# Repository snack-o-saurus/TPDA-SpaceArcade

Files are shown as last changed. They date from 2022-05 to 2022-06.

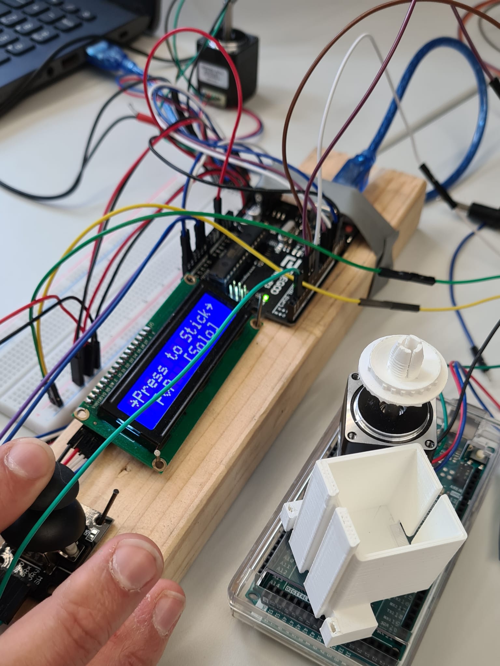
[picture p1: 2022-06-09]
Documentation/Pictures/Teiletest aus dem Druck-1/Teiltest-Testdruck1.jpeg

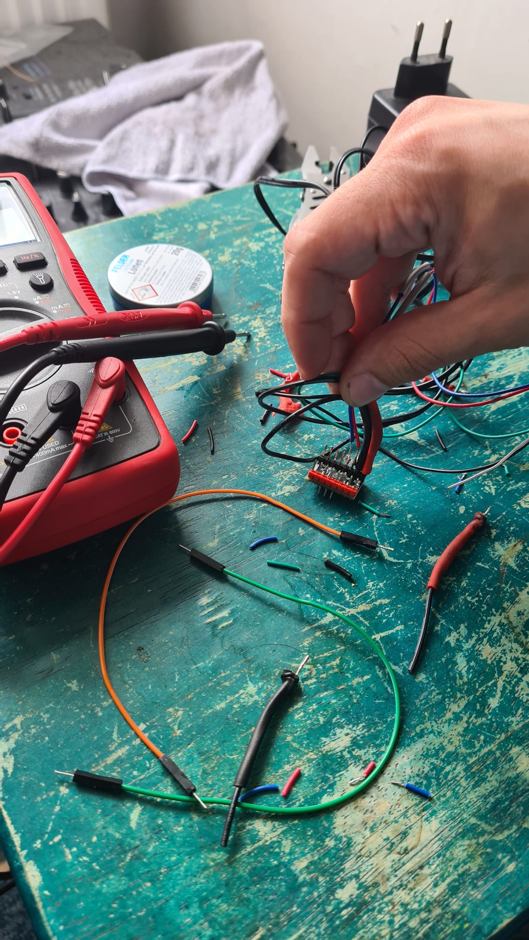
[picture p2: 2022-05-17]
Documentation/Testen-der-Schaltung-02.jpeg

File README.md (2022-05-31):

# TPDA-SpaceArcade

Gruppe 5: TPDA-W21-Oos-SpaceInvadersArcade

DEADLINE: 18. JUNI 2022
GAME JAM: 22. JUNI 2022

THIS IS THE OFFICIAL EXAM PROJECT OF THE TECHNICAL PROJECT W21 COURSE
OOMENS - TAEFI

Space Invaders Arcade Machine - Arduino Firmware Code

Dokumentation des TMC-2208-Treibers: https://github.com/teemuatlut/TMCStepper/blob/74e8e6881adc9241c2e626071e7328d7652f361a/README.md

Hier finden Sie alle nützlichen Informationen und Quellenangaben zur Umsetzung des Codes.

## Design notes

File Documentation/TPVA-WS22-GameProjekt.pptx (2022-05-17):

## TPV: Gruppe A – Oomens, Taefi Projekt: Entwicklung eines eingebetteten Games

Anselm Fritzsche – 0800-XXX
Mats Althaus – 2557483

13. Januar 2022

## Spielziel & Konzept

- Phase 1: Entwicklung eines Space Invaders – Emulators mithilfe eines Displays und eines Joysticks sowie zwei Tastern

Phase 2: Implementieren eines zweiten Terminals mit Bedienelementen – Entwicklung von Coop- und PVP-Modi

Phase 3: Entwickeln eines Interfaces mit Geschützturm, Luftballons und Zielen (angelehnt an „Jahrmarkt- bzw. Arcade-Prinzip“)

## Projektplan

Datum / Meilenstein | Ziel
13.01.2022 | Ideenfindung, Design und Projektplanung (Termine)
20.01.2022 | Projektanalyse, Entwicklung des Konzepts, Schaltskizze, Use Case-Diagramm, Aktivitätsdiagramme, Festlegen des Spielziels, Entwicklung von Konzept & Bedienkonzept
27.01 2022 | Vorstellung des Projekts: Erreichen des 1/3 − Meilensteins (1)
03.02.2022
10.02.2022
17.02.2022
24.02.2022
03.03.2022
10.03.2022
17.03.2022
24.03.2022
31.03.2022
07.04.2022
14.04.2022
21.04.2022
28.04.2022
05.05.2022 | Poster mit Bedienungsanleitung (?!), Upload des Codes

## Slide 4

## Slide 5

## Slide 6

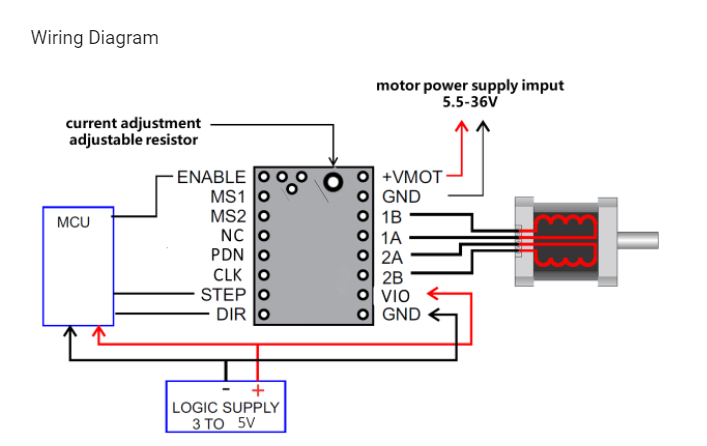
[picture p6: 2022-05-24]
schematic/TMC-2208-Interfaceschematic.png

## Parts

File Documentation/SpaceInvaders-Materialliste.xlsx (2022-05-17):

 | Space Invaders-Simulator: Materialliste
 |  |  | Option 1: Schrittmotoren, evidence based proof
Menge | Bezeichnung | Preis/Stk | Bezug | Summe
1 | 3D-Drucker-Bausatz (inkl. 4x Schrittmotor, Treiber, 2. Arduino Uno | 44.28 € | https://www.wish.com/search/stepper%20motor/product/5d71d7c4bddcd87e079ee16d?position=0&share=web | 44.28 €
10 | Hall-Sensor (10Stk@5,00€) | 0.50 € | https://www.wish.com/search/hall%20sensor/product/610667652d587eca89de3e1e?position=1&share=web | 5.00 €
1 | NERF-Pistole zum Zerlegen | 4.50 € | https://www.ebay.de/itm/194788540224?hash=item2d5a4d3f40:g:pGcAAOSw4N1h-Wlu | 4.50 €
1 | TFT-Display für Uno R3 | 8.00 € | https://www.wish.com/search/tft%20display/product/60056a0869809fbace21e8d7?position=6&share=web | 8.00 €
 |  |  | vorauss. Versandkosten: | 10.00 €
 |  |  | vorauss. Gesamtsumme: | 71.78 €
 |  |  | Option 2: Getriebemotoren, PWM-Regelung (stufenlos), Umsetzung nach Plan
2 | 12V-Getriebemotor mit Spindel | 7.95 € | https://www.pollin.de/p/getriebemotor-5503740-12v-spindel-310842 | 15.90 €
2 | 12V / 32mA DC Schrittmotor, Winkel 5,625 | 12.95 € | https://de.elv.com/schrittmotor-12-v-dc-32-ma-winkel-5625-64-schritte-109085?fs=3090392678&c=487 | 25.90 €
1 | Arduino MotorShield (Motortreiber) | 12.95 € | https://www.pollin.de/p/joy-it-motorshield-fuer-arduino-810662 | 15.50 €
10 | INFINEON Hallsensor TLE 4905L | 0.62 € | https://de.elv.com/infineon-hallsensor-tle-4905l-109561?fs=3255545492&c=840 | 6.20 €
1 | AU-Optronics M156XW01 LC-TFT-Display 1366x768@15,6" | 9.95 € | https://www.pollin.de/p/lc-display-au-optronics-m156xw01-15-6-16-9-lvds-121776 | 9.95 €
1 | NERF-Pistole zum Zerlegen | 4.50 € | https://www.ebay.de/itm/194788540224?hash=item2d5a4d3f40:g:pGcAAOSw4N1h-Wlu | 4.50 €
 |  |  | vorauss. Versandkosten: | 15.00 €
 |  |  | vorauss. Gesamtsumme: | 92.95 €
 |  |  | = lange Lieferzeit
 |  |  | = Alternative

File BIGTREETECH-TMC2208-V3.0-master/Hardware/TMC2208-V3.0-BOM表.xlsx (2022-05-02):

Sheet: Sheet1
TMC2208-V3.0 BOM表
物料编号 | 元件型号 | 元件丝印位置 | 元件封装 | 数量 | 备注
贴片料
DDZ000046 | 0.11R 1% | R6, R7 | 0805R | 2 | 贴片电阻
DDZ000082 | 0R | J2 | 0402A | 1 | UART
DDZ000077 | 20K | R1, R2, R3, R5 | 0402A | 4 | 贴片电阻
DDW000019 | 20K | RP1 | VR6 | 1 | 可调电位器
DDR000033 | 0.1UF/50V/±10% | C1, C3, C5, C6 | 0402A | 4 | 贴片电容
DDR000022 | 10UF/50V/±10% | C7 | 0603N | 1 | 贴片电容
DDR000052 | 22NF/50V/±10% | C4 | 0402A | 1 | 贴片电容
DDR000037 | 4.7UF/10V/±10% | C2 | 0402A | 1 | 贴片电容
DIC000049 | TMC2208 | IC1 | QFN28 | 1 | IC
DPC000150 | TMC2208-V3.0 |  |  | 1 | PCB
制表： 姜坤 批准：
时间：2019.3.30 时间：

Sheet: Sheet2
插件料
物料编号 | 元件型号 | 元件丝印位置 | 元件封装 | 数量 | 备注
DPZ000249 | 8Pin 2.54mm | JP1 | 8HEARD | 1 | 黑色镀金单排排针
DPZ000250 | 8Pin 2.54mm | JP2 | 8HEARD | 1 | 蓝色镀金单排排针
BQT000034 | 防静电盒 |  |  | 1 | 包装袋盒
MPA000109 | TMC2208-V3.0 |  |  | 1 | PCBA
WSR000012 | 散热片 |  | 9*9*12 | 1 | 黑色散热片
BQT000043 | TMC2208卡片 |  |  | 1
制表： 姜坤 批准：
时间：2019.3.30 时间：

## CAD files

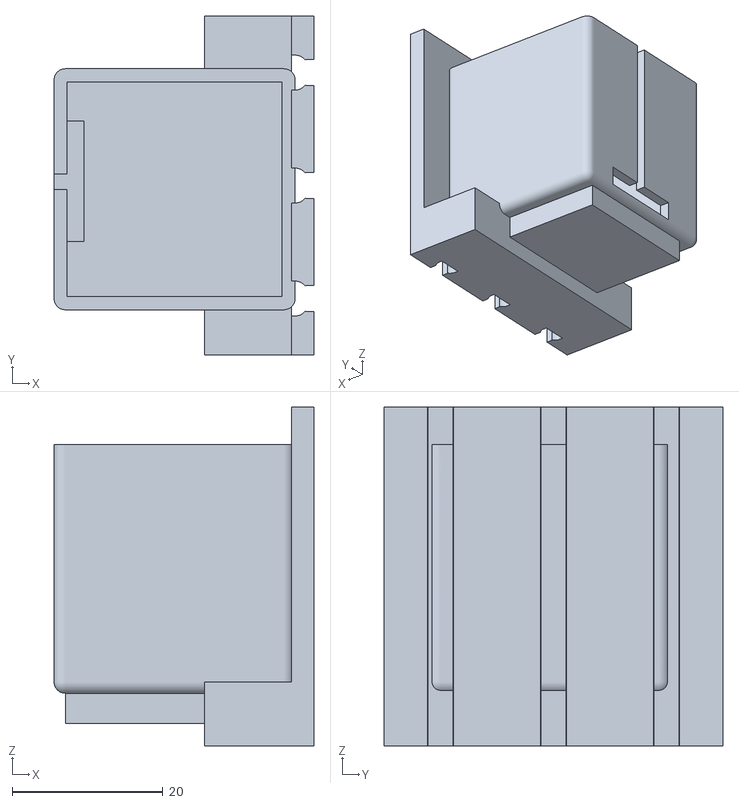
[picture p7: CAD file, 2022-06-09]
models/Druck01_v3/Motor-PAN-Case-v3.stl
34.5 x 45.0 x 45.0

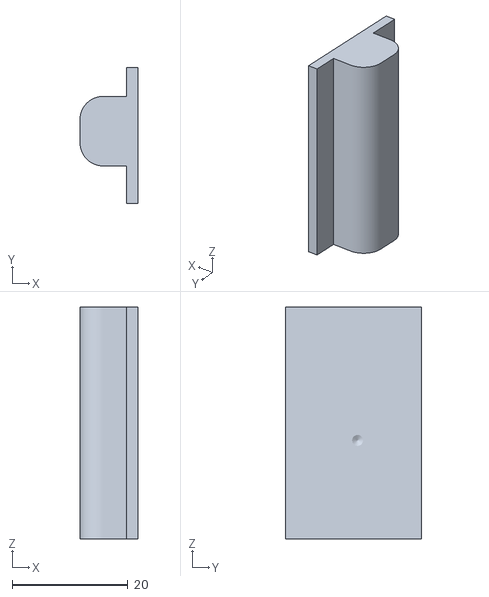
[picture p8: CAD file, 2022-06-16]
models/Druck02_v3/Stempel-R.stl
10.0 x 23.5 x 40.0

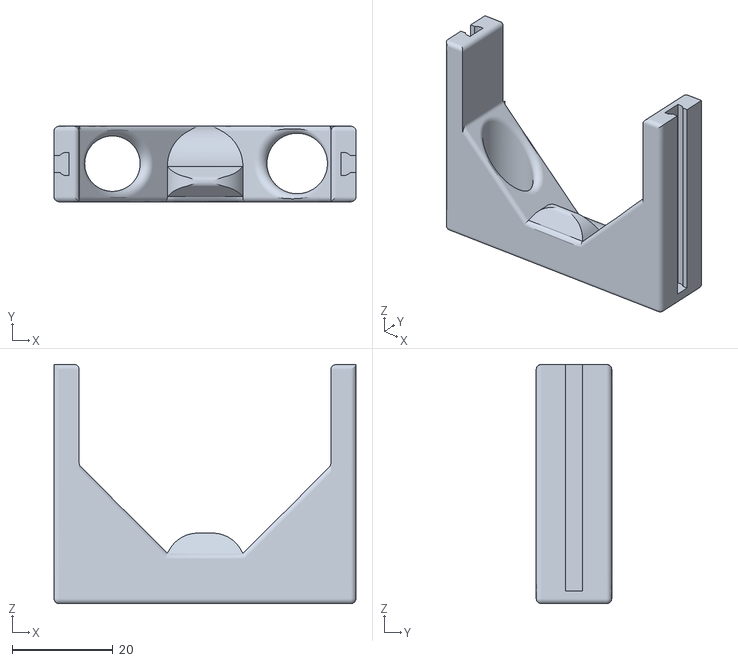
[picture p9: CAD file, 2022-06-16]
models/Prototype #1/Nerfhalter-Grip-v3.stl
60.0 x 15.0 x 47.5

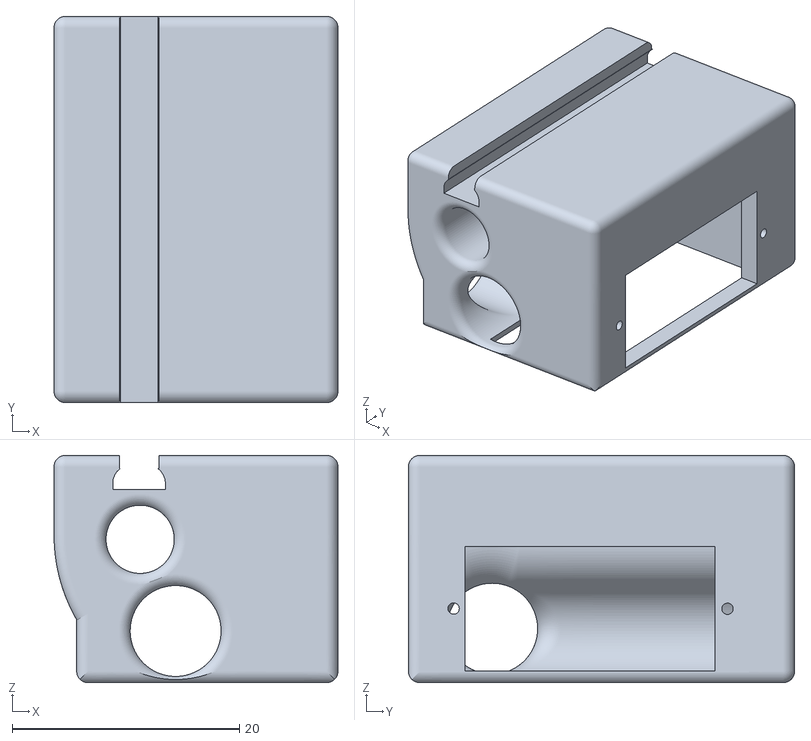
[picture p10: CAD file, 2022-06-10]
models/Prototype #2/Servobefestigung-v5.stl
25.0 x 34.0 x 20.0

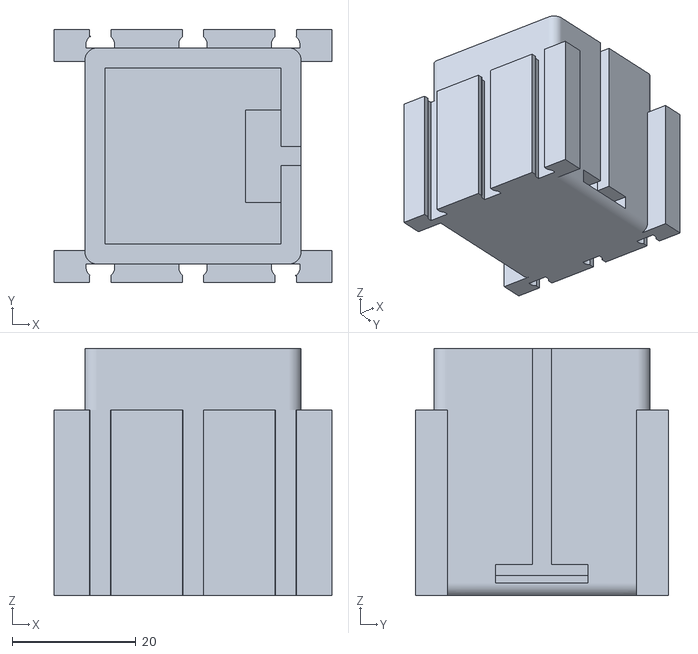
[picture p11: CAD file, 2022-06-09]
models/Druck01_v3/Motor-TILT-Case-v3.stl
45.0 x 41.0 x 40.0

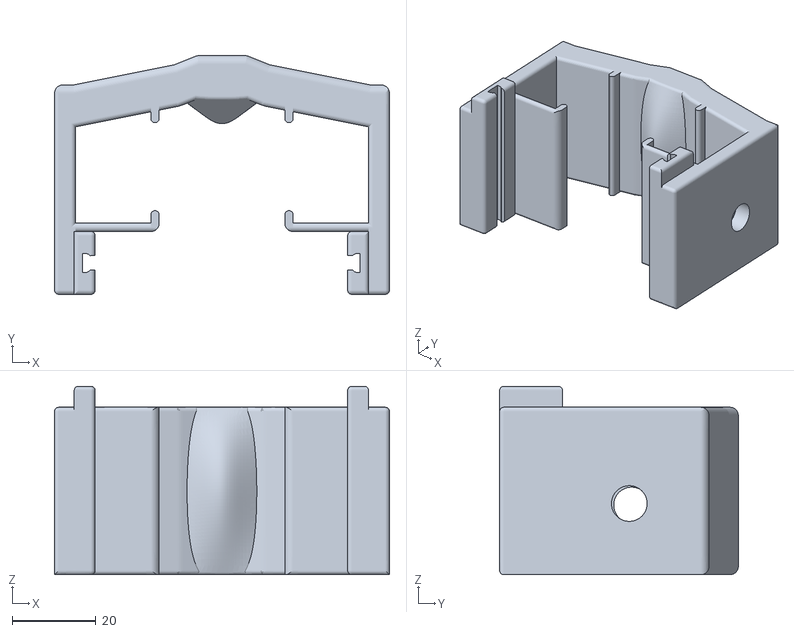
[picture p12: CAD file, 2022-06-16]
models/Druck02_v3/Laufhalter-NERF-v2.stl
80.0 x 57.0 x 45.0

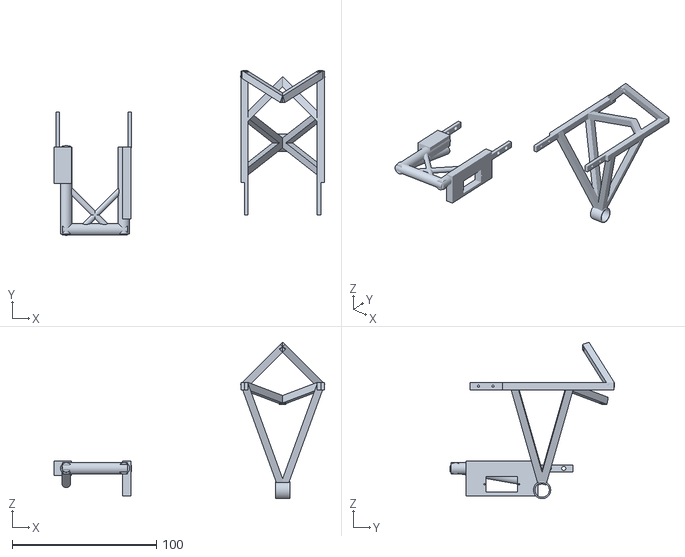
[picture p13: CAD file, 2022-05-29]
models/Prototype #1/NerfTurret-ProTyp-Fixation-4-v2.stl
187.9 x 114.1 x 108.4

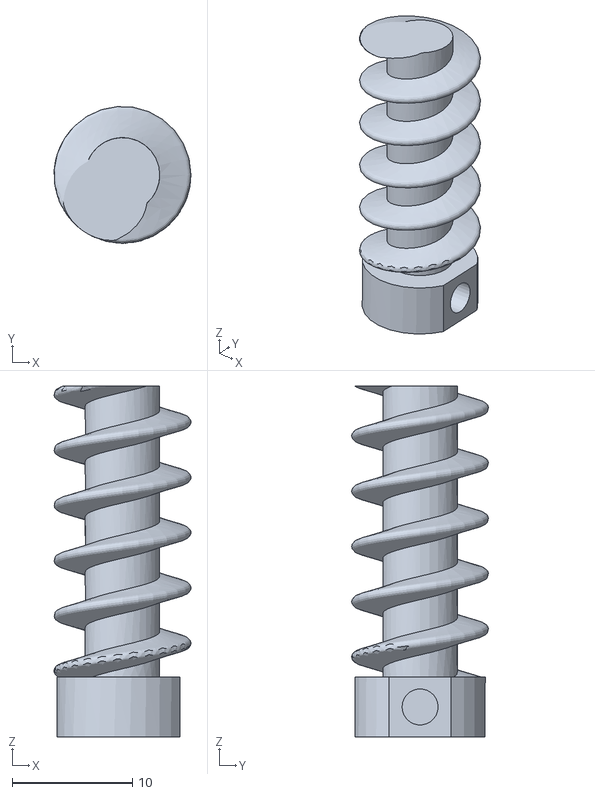
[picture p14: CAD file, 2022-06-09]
models/Druck01_v3/Wormgear-Adaptor-v3.stl
11.4 x 11.4 x 29.2

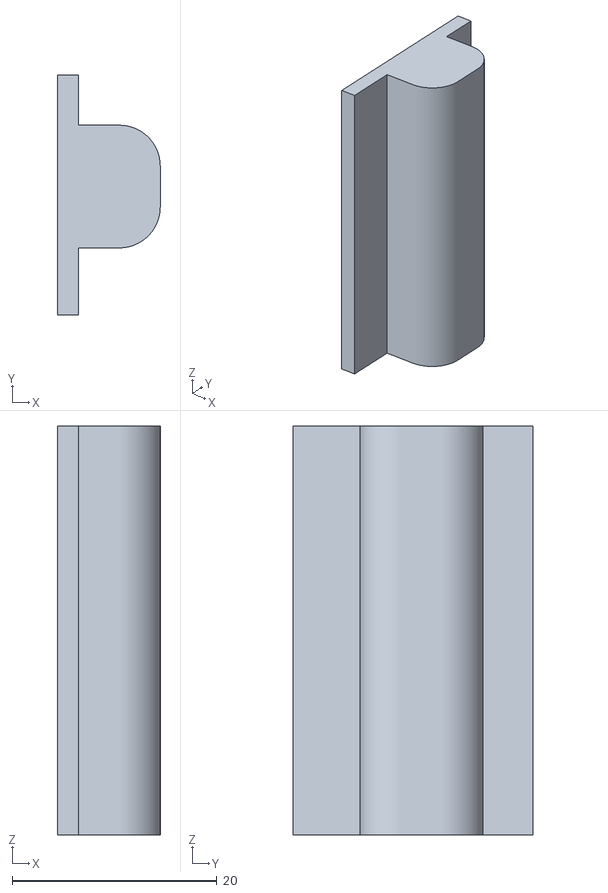
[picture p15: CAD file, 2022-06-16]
models/Druck02_v3/Stempel-L.stl
10.0 x 23.5 x 40.0

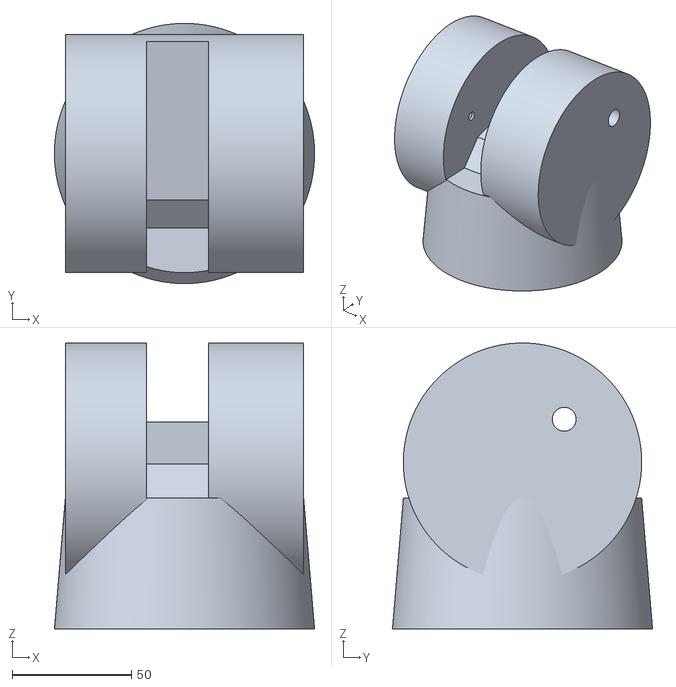
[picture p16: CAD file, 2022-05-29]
models/Prototype #1/NerfTurret-ProTyp-Turret-2-v2.stl
109.2 x 109.2 x 120.0

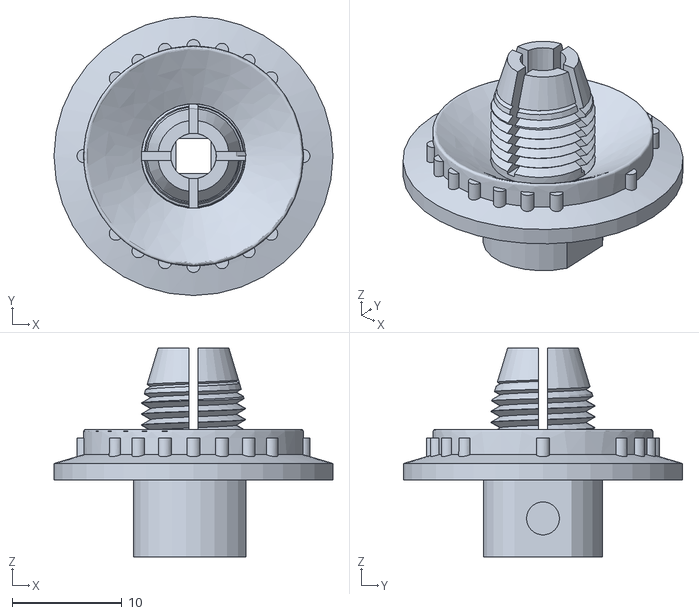
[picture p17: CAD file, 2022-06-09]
models/Druck01_v3/Gear-Adaptor-v3.stl
25.4 x 25.4 x 19.0

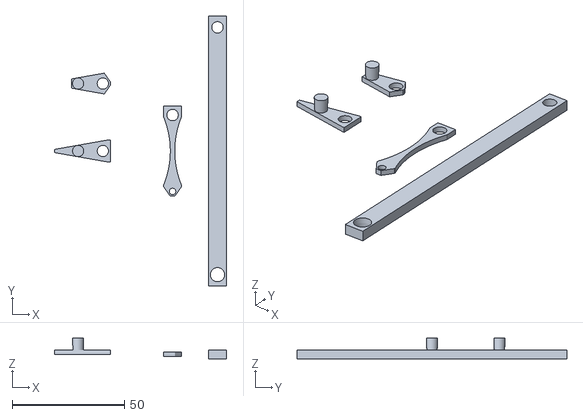
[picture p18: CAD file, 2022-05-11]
models/Prototype #1/NerfTurret-ProTyp-Connectors-3.stl
76.5 x 120.0 x 9.25

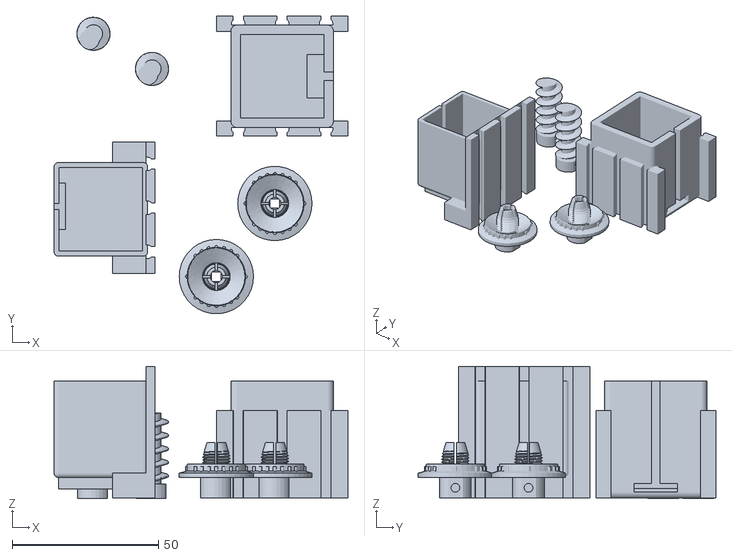
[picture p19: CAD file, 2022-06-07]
models/Druck01_v3/SpaceParts-v3.stl
100.5 x 101.7 x 45.2

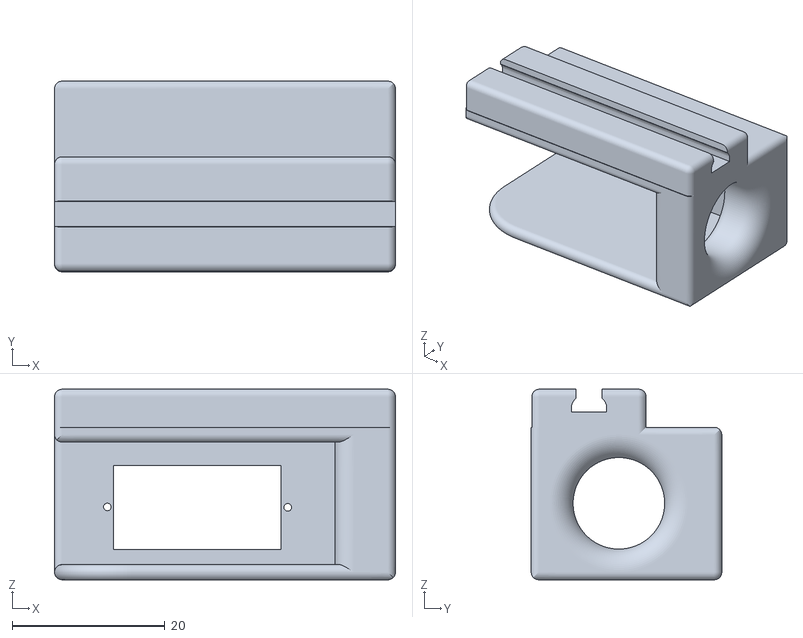
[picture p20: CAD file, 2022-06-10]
models/Druck02_v3/Servohalter-v4.stl
44.7 x 25.0 x 25.0

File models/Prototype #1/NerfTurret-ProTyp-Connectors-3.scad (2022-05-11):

$fn = 250;

//Adapter fuer Motorwelle PAN
difference(){
translate([-200,0,1]){cube([25,10,2], center=true);}
translate([-200,8,1]){
    rotate([0,0,10]){cube([40,10,3], center=true);}}
translate([-200,-8,1]){
    rotate([0,0,-10]){cube([40,10,3], center=true);}}
translate([-191,0,1]){cylinder(12,2.5,2.5,true);}}
translate([-202,0,4.5]){cylinder(5.5,2.3,2.5,true);}
//----------------------------------------------------------
//Adapter fuer Motorwelle TILT
difference(){
translate([-200,30,1]){cube([25,10,2], center=true);}
translate([-200,38,1]){ rotate([0,0,10]){
    cube([40,10,3], center=true);}}
translate([-200,22,1]){ rotate([0,0,-10]){
    cube([40,10,3], center=true);}}
translate([-180.5,38,1]){ rotate([0,0,35]){
    cube([20,10,3], center=true);}}
translate([-180.5,22,1]){ rotate([0,0,-35]){
    cube([20,10,3], center=true);}}
translate([-191,30,1]){cylinder(12,2.5,2.5,true);}
translate([-210,30,1]){cube([10,10,3], center=true);}
}
translate([-202,30,4.5]){cylinder(5.5,2.3,2.5,true);}
//----------------------------------------------------------
//Verbindungsstange PAN
//TODO: Radien nach Spiel einstellen!!!
difference(){
translate([-140,0,0]){cube([8,120,4], center=true);}
translate([-140,55,0]){cylinder(20,2.5,2.6,center=true);}
translate([-140,-55,0]){cylinder(20,2.5,3.8,center=true);}
translate([-140,-55,0]){cylinder(20,3.8,2.5,center=true);}
}
//-----------------------------------------------------------
//Verbindungsstange TILT
//TODO: Radien nach Spiel einstellen!!!
difference(){
translate([-160,0,0]){cube([8,40,2], center=true);}
translate([-160,16,0]){cylinder(20,2.5,2.6,center=true);}
translate([-160,-18,0]){cylinder(10,1.2,1.7,center=true);}
translate([-160,-18,0]){cylinder(10,1.7,1.2,center=true);}
translate([-166.5,-21,0]){    rotate([0,0,-55]){
    cube([10,10,3],center=true);}}
translate([-153.5,-21,0]){    rotate([0,0,55]){
    cube([10,10,3],center=true);}}
translate([-201,0,0]){cylinder(10,40,40,center=true);}
translate([-119,0,0]){cylinder(10,40,40,center=true);}
}

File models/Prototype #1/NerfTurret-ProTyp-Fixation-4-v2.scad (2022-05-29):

$fn = 300;

//Halterung NERF
 rotate([0,90,0]){
 difference(){  cylinder(10,6,6,center=true);  
                cylinder(11,5,5,center=true);}}
                
//Nerfhalter v.2 [Anforderungen prov. by Oos, 
//neuer Prototyp sei erforderlich zur Druckoptimierung]
// >>24/5/22
//------------------------------------------------------------
//VL                
translate([-14,10,39]){ rotate([-15,-20,0]){
  cube([5,5,75],center=true);   }}
//VR
translate([14,10,39]){ rotate([-15,20,0]){
  cube([5,5,75],center=true);   }}
//HL
translate([-14,-10,39]){ rotate([15,-20,0]){
  cube([5,5,75],center=true);   }}
//HR
translate([14,-10,39]){ rotate([15,20,0]){
  cube([5,5,75],center=true);   }}
//RL
difference(){
translate([-26.5,0,72]){  rotate([0,0,0]){
  cube([5,100,5],center=true);  }}
translate([-30,-40,72]){   rotate([0,0,0]){
  cube([7,25,7],center=true);   }}
translate([0,-44,72]){   rotate([0,90,0]){
 cylinder(60,0.75,0.75,center=true);  }}
translate([0,-34,72]){   rotate([0,90,0]){
 cylinder(60,0.75,0.75,center=true);  }}}
//RR
  difference(){
translate([26.5,0,72]){  rotate([0,0,0]){
  cube([5,100,5],center=true);  }}
translate([30,-40,72]){  rotate([0,0,0]){
  cube([7,25,7],center=true);   }}
translate([0,-44,72]){   rotate([0,90,0]){
 cylinder(60,0.75,0.75,center=true);  }}
translate([0,-34,72]){   rotate([0,90,0]){
 cylinder(60,0.75,0.75,center=true);  }}}
//LC
translate([-12.5,30,67]){    rotate([-15,0,-45]){
    cube([5,40,5],center=true); }}
translate([12.5,30,67]){    rotate([-15,0,45]){
    cube([5,40,5],center=true); }}
//STC
translate([-13,39,86]){   rotate([-66,45,0]){
    cube([5,43,5],center=true); }}
translate([13,39,86]){   rotate([-66,-45,0]){
    cube([5,43,5],center=true); }}
//---------------------------------------------------------
//Back frame
translate([-150,0,0]){    union(){
translate([40,-33,15]){  rotate([90,0,0]){
    cylinder(60,4,4,center=true);}}
translate([0,-33,15]){  rotate([90,0,0]){
    cylinder(60,4,4,center=true);}}
translate([20,-60,15]){  rotate([90,0,90]){
    cylinder(45,4,4,center=true);}}
translate([15,-45,15]){  rotate([90,0,45]){
    cylinder(45,2,2,center=true);}}
translate([25,-45,15]){  rotate([90,0,-45]){
    cylinder(45,2,2,center=true);}}
translate([0,-33,10]){  rotate([80,0,0]){
    cylinder(62,3,3,center=true);}}
    
difference(){
translate([44,8.8,15]){  rotate([0,0,0]){
   cube([2.5,25,5],center=true);}}
translate([44,15,15]){  rotate([0,90,0]){
   cylinder(50,1.45,1.45,center=true);}}
translate([44,5,15]){  rotate([0,90,0]){
   cylinder(50,1.45,1.45,center=true);}}
}
difference(){
translate([-6,8.8,15]){  rotate([0,0,0]){
   cube([2.5,25,5],center=true);
}}
translate([-6,15,15]){  rotate([0,90,0]){
   cylinder(50,1.45,1.45,center=true);}}
   
translate([-6,5,15]){  rotate([0,90,0]){
   cylinder(50,1.45,1.45,center=true);}}
}


translate([-2.5,-15.5,15]){  rotate([0,0,0]){
   cube([12,25,10],center=true);
}}

//Aufnahme fuer Triggerservo
difference(){
translate([42,-27.9,8]){cube([6,50,24],center=true);}
translate([42,-27.9,4]){cube([10,22,11],center=true);}
translate([42,-16,4]){  rotate([0,90,0]){
    cylinder(8,0.5,0.5,center=true);}}
translate([42,-40,4]){  rotate([0,90,0]){
    cylinder(8,0.5,0.5,center=true);}}
}
}}

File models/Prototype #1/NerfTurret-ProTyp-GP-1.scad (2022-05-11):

$fn=150; //Auflösung

//Erstellen der Grundplatte mit Nut
union(){    difference(){
cube([200,180,40], center=true);
//Aussparung für PAN-Servomotor 
 translate([60,60,0]){cube([29,29,45], center=true);} 
 translate([60,85,-22]){cube([5,25,10], center=true);}
 
 //Nut
 translate([0,0,37]){    
  difference(){   
    cylinder(h=40,r=50, center=true);
    cylinder(h=40,r=45, center=true); }}}
    
translate([44.5,60,22]){cube([2,30,5], center=true); } 
translate([75.5,60,22]){cube([2,30,5], center=true); } 
//Top plate for engine screwdown       
difference(){  
 translate([60,60,25]){cube([33,30,2], center=true);}  
    // 1/1000 clearance for engine shaft 
 translate([60,60,25]){cylinder(5, 2.6, center=true);}
    //Screwdown points
 translate([50,70,25]){cylinder(5, 2.5, center=true);}
 translate([70,70,25]){cylinder(5, 2.5, center=true);}
 translate([70,50,25]){cylinder(5, 2.5, center=true);}
 translate([50,50,25]){cylinder(5, 2.5, center=true);}
 }
}

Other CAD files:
models/Druck02_v3/Nerfhalter-Grip-v3.stl
models/Prototype #1/NerfTurret-ProTyp-GP-1.stl
models/Prototype #1/NerfTurret-ProTyp.stl
models/Prototype #1/NerfTurret-ProTyp-Turret-2.stl
models/Prototype #1/NerfTurret-ProTyp-Turret-2-v2.scad
models/Prototype #1/NerfTurret-ProTyp-Fixation-4.scad
models/Prototype #1/NerfTurret-ProTyp-Turret-2.scad
models/Prototype #1/NerfTurret-ProTyp.scad
models/Prototype #1/NerfTurret.scad

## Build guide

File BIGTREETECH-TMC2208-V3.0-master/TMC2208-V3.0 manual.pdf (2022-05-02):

Shenzhen BIGTREE technology co., LTD. BIG TREE TECH

# BIGTREETECH

# TMC2208-V3.0

# Stepper motor driver

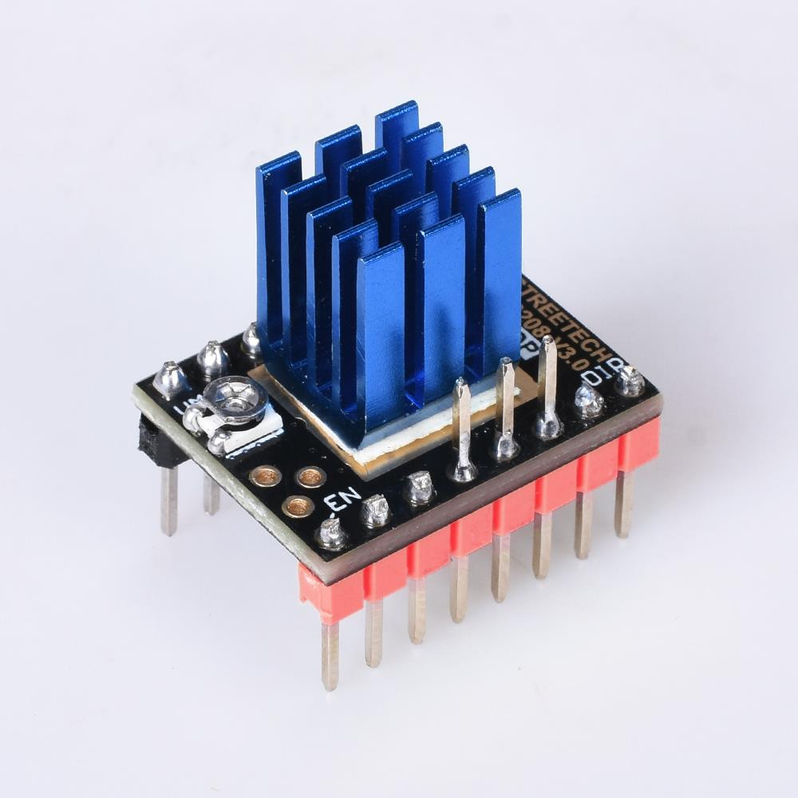
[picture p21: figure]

BIG TREE TECH

Parameter description

power tube built-in drive current 1.2A ,peak current 2A 256 microsteps per fullstep
interpolation from lower input resolutions stealthChop2 - for quiet positioning
spreadCycle - for high speed and high dynamics
Low RDSon LS 280mΩ & HS 290mΩ (typ. at 25°C) Voltage Range 12V/24VDC
Single Wire UART for advanced configuration options Integrated Pulse Generator for standalone motion

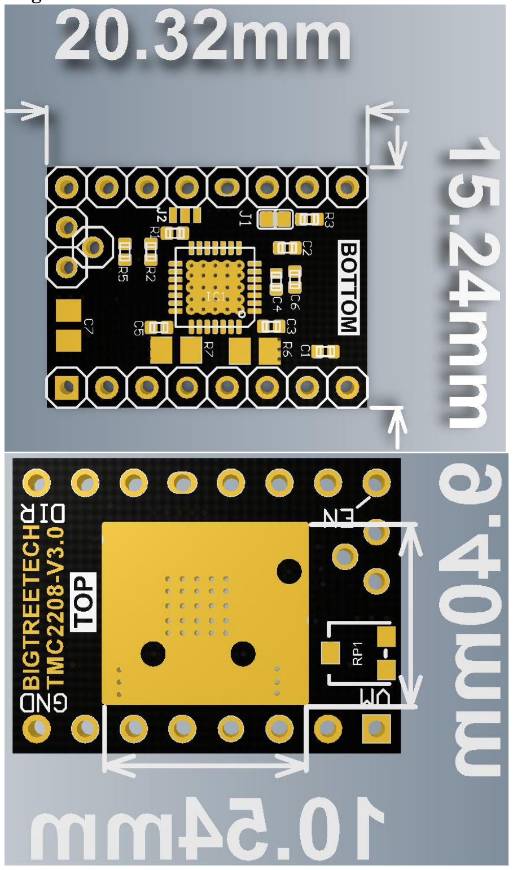
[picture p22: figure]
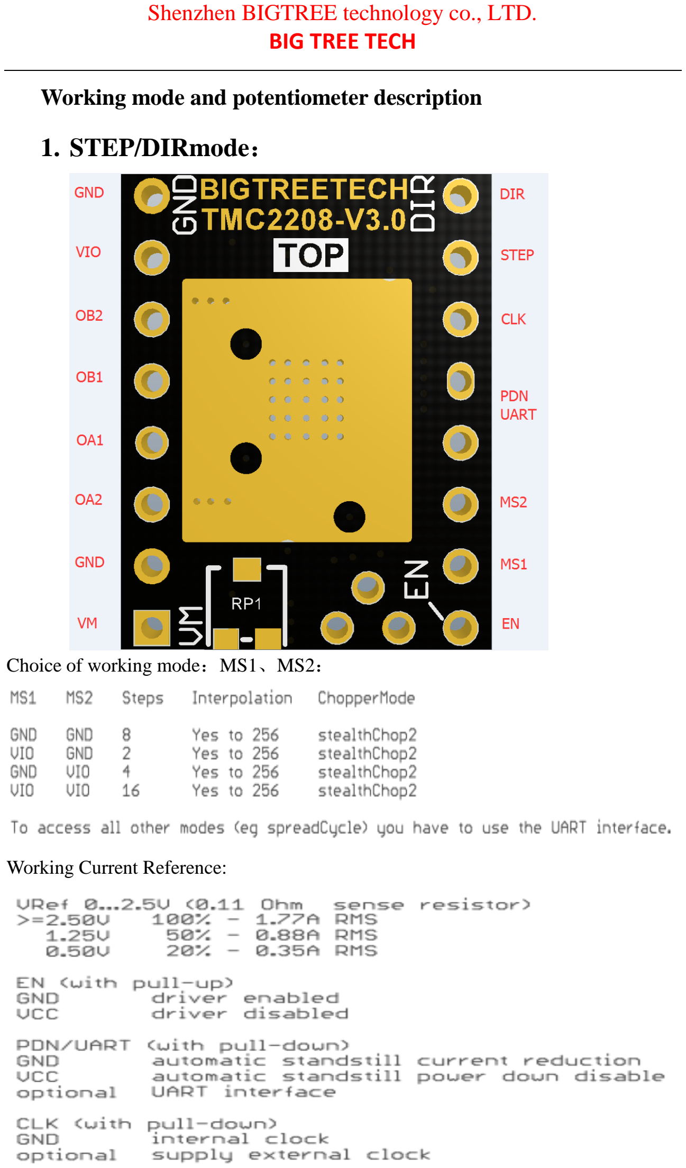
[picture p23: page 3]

BIG TREE TECH

Working mode and potentiometer description

### 1. STEP/DIRmode：

Choice of working mode：MS1、MS2：

Working Current Reference:

BIG TREE TECH

2.UART mode：

Note: TMC2208 v3.0 has two modes from our factory : step / dir and UART mode. Customers can choose according to your own needs.
The user who purchases the step / dir mode driver shall perform the following hardwa re operations on the driver module before wiring (the user who purchases the UART mode driver does not need any welding operations):
Weld J2 as shown in the purple area, and put the driver in UART mode.

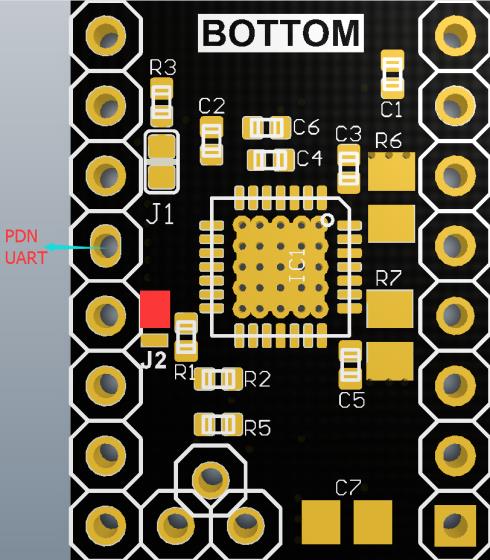
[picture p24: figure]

The benefits of UART mode:

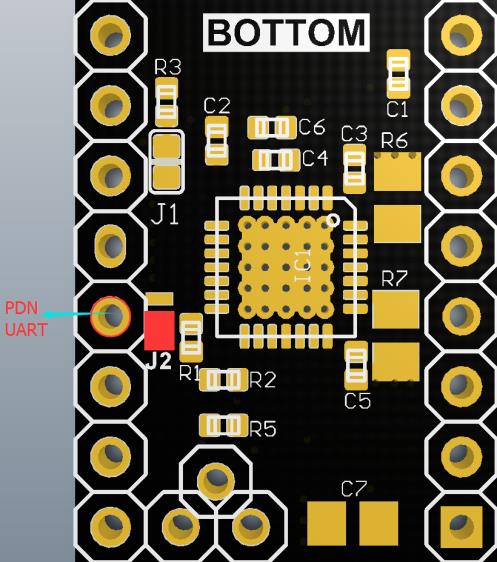
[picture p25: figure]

1.Motor current can be set arbitrarily by firmware.
2.Micro-steps can be set arbitrarily by firmware (up to 256 actual micro-steps);
3.The actual and interpolated microsteps can be combined to achieve maximum torque.
4.Firmware can dynamically switch stepper motors between stealthChop2 and spreadCycle modes through UART.
5.When the motor is not moving, the standby current of the motor can be reduced dynamically (through UART).

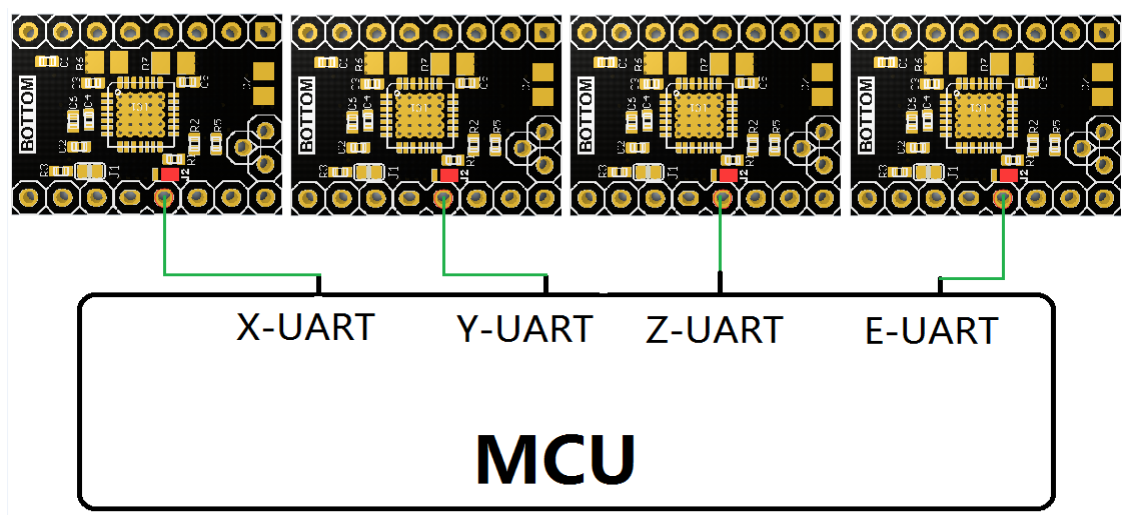
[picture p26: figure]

BIG TREE TECH

Potentiometer regulation instructions:

Clockwise Rotating Potentiometer - Reduces Vref, thereby reducing drive

current;

Counterclockwise rotating potentiometer - Increase Vref, thereby

increasing the driving current.

The accurate voltage of Vref can only be measured when the main

board is supplied with 12V or 24V voltage.

The range of Vref value: default value: 1V (+0.2); MAX: 2V; MIN:

0V;

Rotating potentiometer must not use too much force to prevent

irreversible damage to the potentiometer; when the counter-clockwise

rotation reaches the maximum, if it continues to rotate, it will become the

minimum; similarly, when the clockwise rotation reaches the minimum, if

it continues to rotate, it will become the maximum

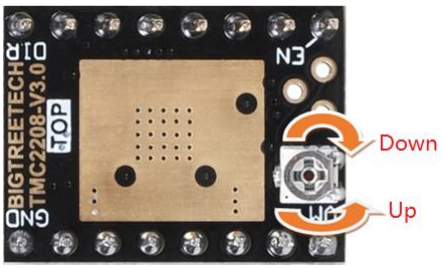
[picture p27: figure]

BIG TREE TECH

Firmware change instructions:

Firmware (marlin-bugfix-2.0)

BIGTREETECH SKR V1.3 as example：

Configuration.h files

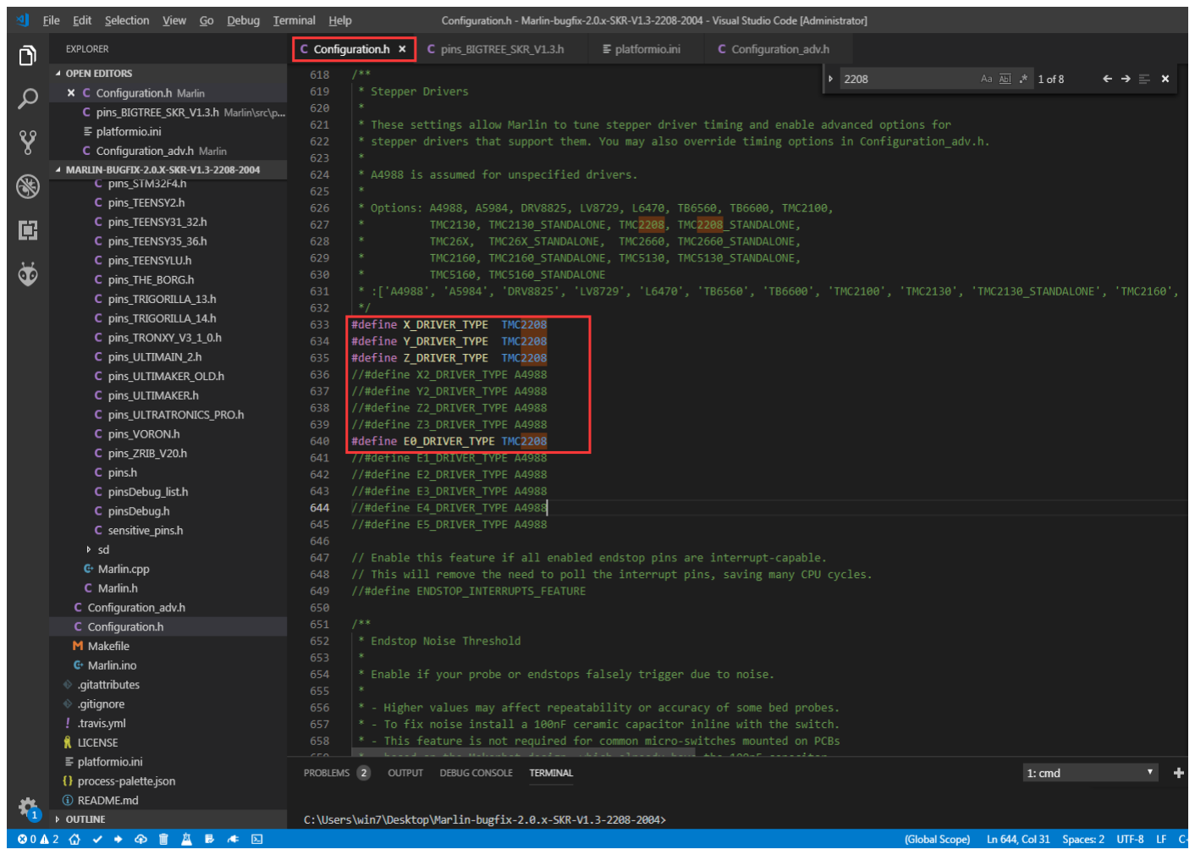
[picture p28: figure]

TMC2208 - means you want to control SilentStepStick through UART.

TMC2208_STANDALONE - does not use UART control but

STEP/DIR .

TMC2208 SilentStepStick，In other words plug and play.

Configuration_adv.h files

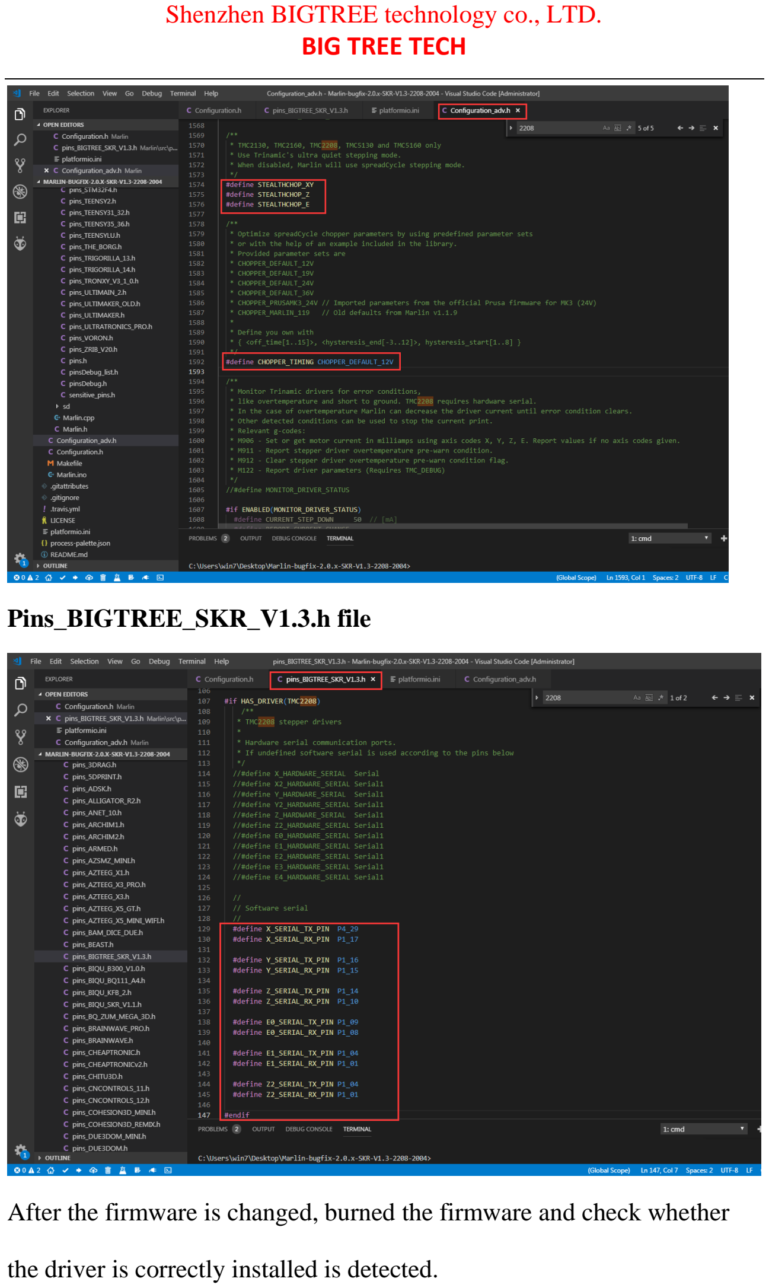
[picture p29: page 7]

BIG TREE TECH

Pins_BIGTREE_SKR_V1.3.h file

After the firmware is changed, burned the firmware and check whether

the driver is correctly installed is detected.

BIG TREE TECH

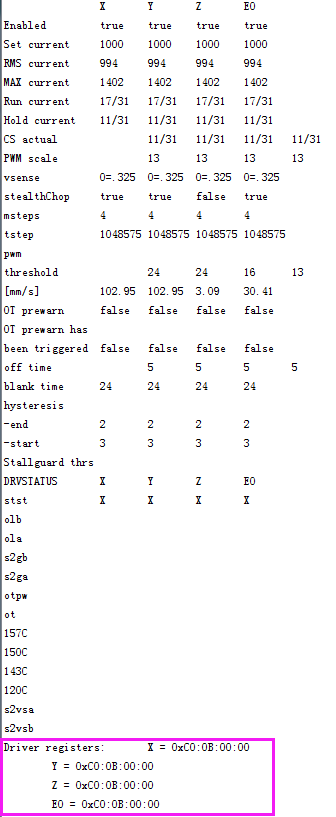
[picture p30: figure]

BIG TREE TECH

Attention ：

1. When hardware chooses UART working mode, cautiously use

soldering iron to prevent scalding hands. After treatment, carefully

observe whether there is residual tin slag in the module. It must be

cleaned up to prevent short circuit burning of the module.

2. Pay attention to the line sequence and IO port when wiring. If the

wrong line is connected, the drive will not work.

3. When inserting drive into the main board, pay attention to see the

direction of drive, can not insert backward, to prevent drive from burning.

4.Make sure to do a good job in heat dissipation (heat sink + heat

dissipation fan) before driving to prevent abnormal operation of the drive.

If you encounter problems in use, welcome to contact us, we will be

answer to you ASAP . If you have any good comments or suggestions on

our products, please tell us , we will carefully consider your comments or

Suggestions. Thank you for choosing BIGTREETECH products, thank you!

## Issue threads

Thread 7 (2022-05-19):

Publishing schematic due

snack-o-saurus, 2022-05-19:
Complete schematic after fixing DC motor overheating issue - rewiring probably needed.

Closed 2022-05-30.

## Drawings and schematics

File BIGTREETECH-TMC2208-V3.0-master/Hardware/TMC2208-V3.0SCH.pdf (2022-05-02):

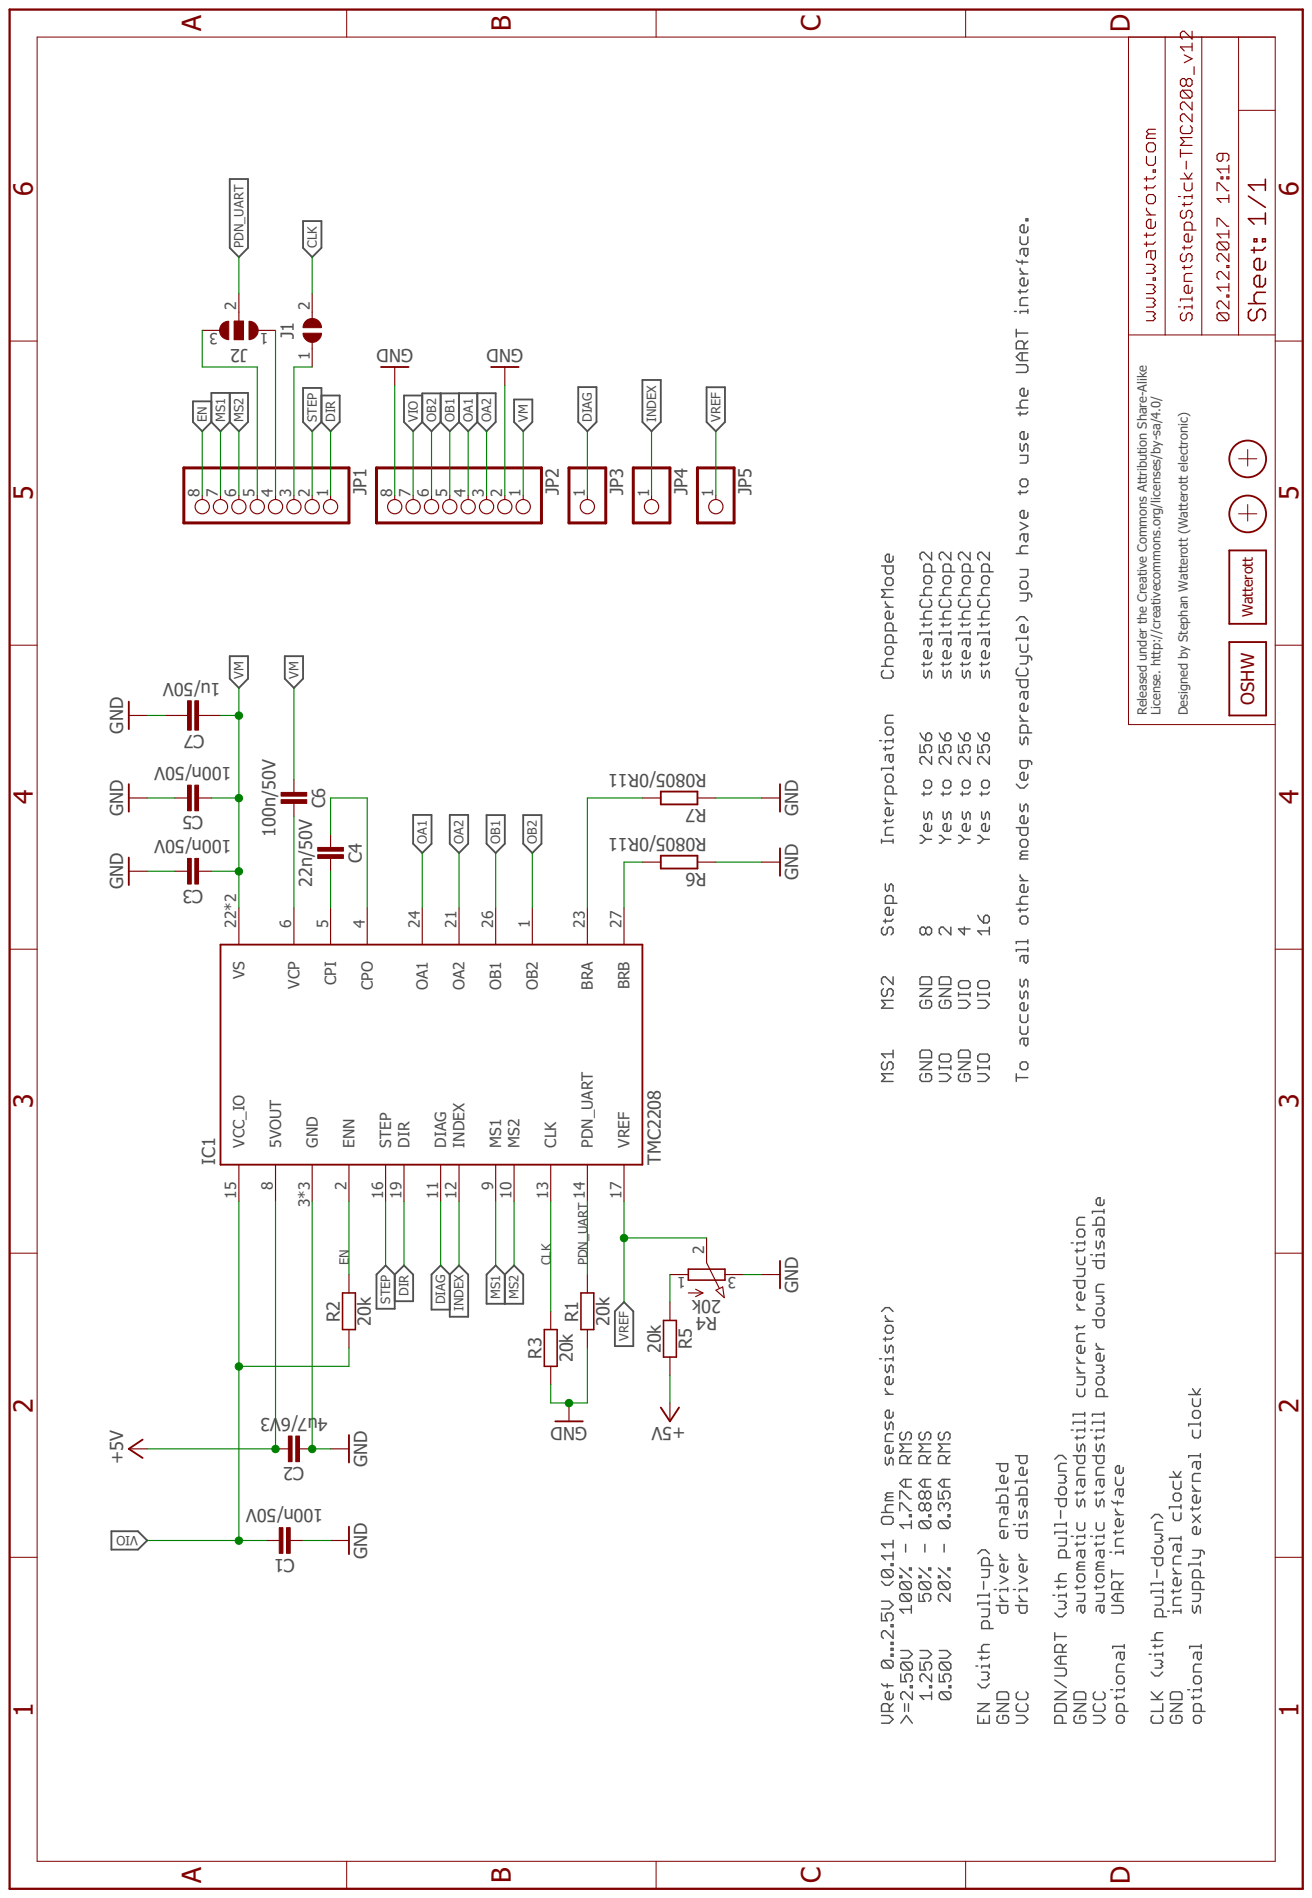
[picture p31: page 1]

DNG DNG GND GND 11R0/ 5080R 11R0/ 5080R GND GND GND V05/ u1 GND +5V V5 + k02 V05/ n001 3V6/ 7u4 V05/ n001 100n/50V 22n/50V 20k DNG20k 20k 20k V05/ n001 GND GND Released under the Creative Commons Attribution Share-Alike License. http://creativecommons.org/licenses/by-sa/4.0/ Designed by Stephan Watterott (Watterott electronic) 87654321JP1 87654321JP2 6R7R 7C 4R 1 3 2 1JP3 1JP4 1JP5 1C2C 3C C6 C4 R5 CLK 13 MS1 9 MS2 10 GND 3*3 PDN_UART 14 STEP 16 DIR 19 VCC_IO 15 OB1 26 BRB 27 OB2 1 VS 22*2 INDEX 12 DIAG 11 ENN 2 VREF 17 5VOUT 8 CPO 4 CPI 5 VCP 6 OA2 21 BRA 23 OA1 24 IC1 TMC2208 R3 R1R2 J1 2 1 5C 2J 3 1 2 DIAG DIAG INDEX INDEX STEP STEP DIR DIR VM VMVM OA1 OA1 OA2 OA2 OB2 OB2 OB1 OB1 VIO OI V VREF VREF MS1 MS1 MS2 MS2 CLK CLK PDN_UART PDN_UART EN EN OSHW Watterott ABCD 1 2 3 4 5 6 ABCD 1 2 3 4 5 6

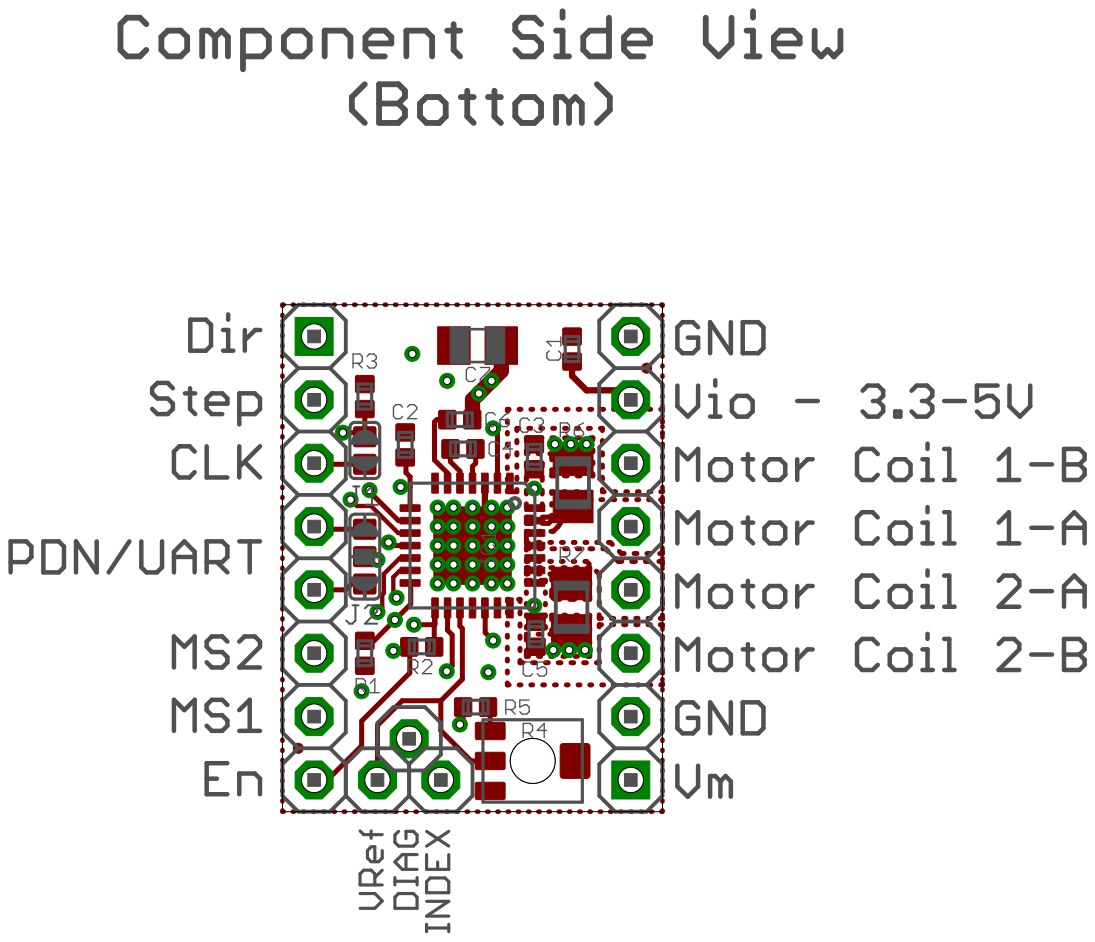
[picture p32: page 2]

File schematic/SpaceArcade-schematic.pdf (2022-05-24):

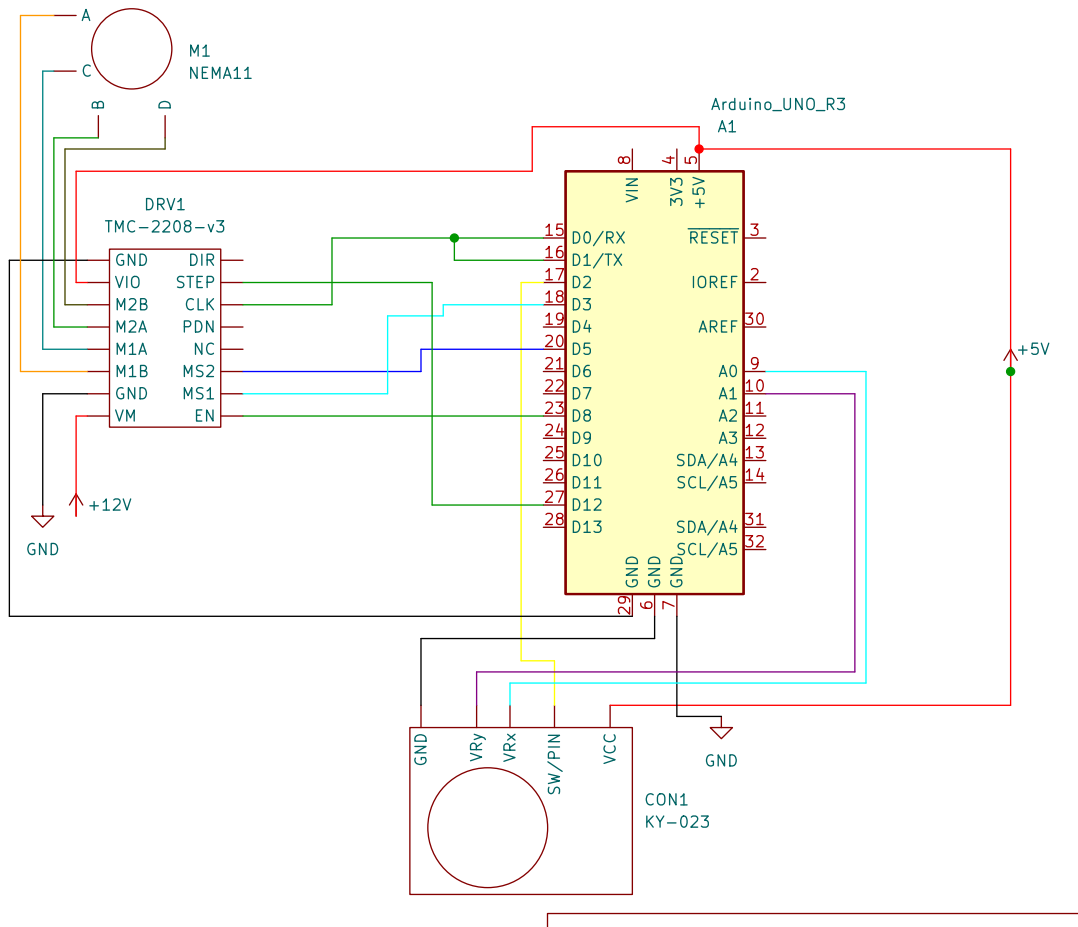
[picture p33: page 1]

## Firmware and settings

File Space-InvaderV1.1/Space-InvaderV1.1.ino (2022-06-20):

#include "Classes.h"
#include "Function.h"
#include "Variable.h"

// https://www.meccanismocomplesso.org/en/lcd1602-using-a-liquid-crystal-display-lcd-with-arduino-via-i2c/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 ( LiquidCrystal_I2C beispielcode mit Contrtoller)
// https://www.arduino.cc/reference/en/libraries/liquidcrystal-i2c/?msclkid=92be2c81b58411ecb6ae3d2d7f275e17( Richtige Library)

// Zeilen können auch mit dem befehl char row1[] oder row2[] angesteuert werden
// Library initialization with 16x2 size settings

// Gameobject(String id, bool control, int score, byte Dir, int xstick, int ystick, int xPin, int yPin, byte swPin)
// target(int thealth, int  tvalue, bool talive, int tscore, int targetid, int trank)
Gameobject p1("", true, 0, 0, 0, 0, XPIN_P1, YPIN_P1, SWPIN_P1);
Gameobject p2("", false, 0, 0, 0, 0, XPIN_P2, YPIN_P2, SWPIN_P2);    // Stickbelegung für Player 2 festlegen
target Alien(2, 0, true, 3, PINT1, MIDDLE);
target Marsianer(1, 0, true, 1, PINT2, EASY);


void setup() {
  Serial.begin(9600);
  pinMode(EN_PIN_PAN, OUTPUT);
  pinMode(STEP_PIN_PAN, OUTPUT);
  pinMode(EN_PIN_TILT, OUTPUT);
  pinMode(STEP_PIN_TILT, OUTPUT);

  pinMode(XPIN_P1,  INPUT);
  pinMode(YPIN_P1,  INPUT);
  pinMode(SWPIN_P1, INPUT);


  pinMode(XPIN_P2,  INPUT);
  pinMode(YPIN_P2,  INPUT);
  pinMode(SWPIN_P2, INPUT);

  pinMode(PINT1, INPUT);
  pinMode(PINT2, INPUT);

  button1.setDebounceTime(100);
  button2.setDebounceTime(100);
  button3.setDebounceTime(100);
  button4.setDebounceTime(100);

  servo.attach(SERVO_PIN);
  lcd.init();
  lcd.backlight();

  digitalWrite(EN_PIN_PAN, HIGH);
  digitalWrite(EN_PIN_TILT, HIGH);
}
void loop() {

  button1.loop();
  button2.loop();
  button3.loop();
  button4.loop();
  button1State = button1.getState();
  button2State = button2.getState();
  button3State = button3.getState();
  button4State = button4.getState();
  p1.getMotion();
  p2.getMotion();
  mainmenu(&p1);
  mainGame();

}


void mainGame() {
  // read Target feedback(hitzone, dead or alife)
  // count Score & save it
  p1.setScore(p1.getScore() + scoregain);
  p2.setScore(p2.getScore() + scoregain);
  Alien.detectHit();
  Alien.readTvalue();
  runtime();
  if (solo == false) {
    enterName(&p1);
    //enterName(&p2);
    scoreboardPVP();
    
    if (p2.getControl() == true) {
      p2.motion();
      pullTrigger();
      if (button1.isReleased()) {
        p2.setControl(false);
        p1.setControl(true);
      }
    }
    if (p1.getControl() == true) {
      p1.motion();
      pullTrigger();
      if (button2.isReleased()) {
        p1.setControl(false);
        p2.setControl(true);
      }
    }
    //start PvP
    //switch controll off turret between p1 & p2
  }
  if (solo == true) {
    selectMod(&p1);
    rulerSOLO();
    enterName(&p1);
    scoreboardSOLO();
    p1.getMotion();
    p1.motion();
    pullTrigger();
    //start Countdown
    //start solo
  }
}
void scoreboardSOLO() {
  lcd.setCursor(0, 3);
  lcd.print("-Scoreboard-");
  lcd.setCursor(1, 2);
  lcd.print("P1: " + p1.getScore());
  lcd.setCursor(1, 9);
  lcd.print("Timer: " + playtime);
}

void scoreboardPVP() {
  lcd.setCursor(0, 3);
  lcd.print("-Scoreboard-");
  lcd.setCursor(1, 2);
  lcd.print("P1: " + p1.getScore());
  lcd.setCursor(1, 10);
  lcd.print("P2: " + p2.getScore());


}

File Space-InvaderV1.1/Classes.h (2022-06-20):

#ifndef CLASSES_H
#define CLASSES_H
#include "libraries.h"
#include "Variable.h"

#define SWPIN_P1 15
#define XPIN_P1 A0
#define YPIN_P1 A1

#define SWPIN_P2 14
#define XPIN_P2 A2
#define YPIN_P2 A3

/* Target recognition */
#define PINT1     A4
#define PINT2     A5
#define PINT3     A6
#define PINT4     A7
#define PINT5     A8



#define STEP_PIN_PAN  10        // Step on rising edge
#define EN_PIN_PAN    12         // LOW = enable driver  / HIGH = disable driver
#define DIR_PIN_PAN   11

#define STEP_PIN_TILT  8        // Step on rising edge
#define EN_PIN_TILT    7        // LOW = enable driver  / HIGH = disable driver
#define DIR_PIN_TILT   6

#define SERVO_PIN      9


#define BUTTON1_PIN     1
#define BUTTON2_PIN     2
#define BUTTON3_PIN     3
#define BUTTON4_PIN     4


ezButton button1(BUTTON1_PIN);
ezButton button2(BUTTON2_PIN);
ezButton button3(BUTTON3_PIN);
ezButton button4(BUTTON4_PIN);


TMC2208Stepper driver = TMC2208Stepper(&Serial);  // Create driver and use
LiquidCrystal_I2C lcd(0x27, 16, 2); // set the LCD address to 0x27
Servo servo;


/*   Implementing object type for targets & score counting      */


class target {
  private:


  public:
    String _tscore;
    int _tvalue;
    int _targetid;
    int _thealth;
    bool _talive = true;
    int _trank;

    target(int thealth, int  tvalue, bool talive, int tscore, int targetid, int trank) {
      setThealth(thealth);
      setTvalue(tvalue);
      setTalive(talive);
      setTargetid(targetid);
      setTrank(trank);
      detectHit();
      readTvalue();

    }

    //   Setter functions
    void setThealth(int thealth) {
      _thealth = thealth;
    }
    void setTvalue(int tvalue) {
      _tvalue = tvalue;
    }
    void setTalive(bool talive) {
      _talive = talive;
      if (_thealth <= 0) {
        _talive = false;
      }
    }
    void setTscore(int tscore) {
      _tscore = tscore;
    }
    void setTargetid(int targetid) {
      _targetid = targetid;
    }
    void setTrank(int trank) {
      _trank = trank;
    }

    //   Getter Functions
    int getThealth() {
      return _thealth;
    }
    int getTvalue() {
      return _tvalue;
    }
    bool getTalive() {
      return _talive;
    }
    int getTid() {
      return _targetid;
    }
    int getTrank() {
      return _trank;
    }
    //    Main Methods
    void detectHit() {
      Serial.println(_tvalue);
      if (_tvalue > 0) {
        _thealth = _thealth - 1;
        switch (_targetid) {
          case HEAVY:
            scoregain = 5;
            lcd.setCursor(0, 0);
            lcd.print("Heavy Target hit");
            if (_thealth > 1) {
              lcd.setCursor(1, 4);
              lcd.print("Try harder!");
            }
            break;
          case MIDDLE:
            scoregain = 3;
            lcd.setCursor(0, 0);
            lcd.print("normal Target hit");
            lcd.setCursor(1, 4 );
            lcd.print("Try harder!");

            break;
          case EASY:
            scoregain = 1;
            lcd.setCursor(0, 0);
            lcd.print("easy Target hit");
            lcd.setCursor(1, 2);
            lcd.print("Almost to easy!");
            break;
          default:
          scoregain = 0;
          break;
        }
      }
    }
    void readTvalue()  {
      _tvalue = analogRead(_targetid);
      Serial.println(_tvalue);
    }
};


class Gameobject {
  public:
    bool _control;
    int _score;
    String _id;
    byte _Dir;
    int _xstick;
    int _ystick;
    int _xPin;
    int _yPin;
    byte _swPin;

    Gameobject(String id, bool control, int score, byte Dir, int xstick, int ystick, int xPin, int yPin, byte swPin) {

      setId(id);
      setControl(control);
      setScore(score);
      setDir(Dir);
      motion();
      getMotion();
      setXstick(xstick);
      setYstick(ystick);
      setXpin(xPin);
      setYpin(yPin);
      setSWpin(swPin);
    }

    //Setter
    void setId(String id) {
      _id = id;
    }
    void setControl(bool control) {
      _control = control;
    }
    void setScore(int score) {
      _score = score;
    }
    void setDir( byte Dir) {
      _Dir = Dir;
    }
    void setXstick(int xstick) {
      _xstick = xstick;
    }
    void setYstick(int ystick) {
      _ystick = ystick;
    }
    void setXpin(int xPin) {
      _xPin = xPin;
    }
    void setYpin(int yPin) {
      _yPin = yPin;
    }
    void setSWpin(byte swPin) {
      _swPin = swPin;
    }
    //Getter
    String getId() {
      return _id;
    }
    bool getControl() {
      return _control;
    }
    int getScore() {
      return _score;
    }
    int getDir() {
      return _Dir;
    }
    int getXstick() {
      return _xstick;
    }
    int getYstick() {
      return _ystick;
    }
    int getXpin() {
      return _xPin;
    }
    int getYpin() {
      return _yPin;
    }
    byte getSWpin() {
      return _swPin;
    }
    //Mainmethods

    void getMotion() {
      yStick_P1 = analogRead(_ystick);               // 0 = LINKS  1023 = RECHTS
      yVal_P1 = map(yStick_P1, 0, 1023, -100, 100);
      xStick_P1 = analogRead(XPIN_P1);               // 0 = OBEN   1023 = UNTEN
      xVal_P1 = map(xStick_P1, 0, 1023, -100, 100);

      yStick_P2 = analogRead(YPIN_P2);               // 0 = LINKS  1023 = RECHTS
      yVal_P2 = map(yStick_P2, 0, 1023, -100, 100);
      xStick_P2 = analogRead(XPIN_P2);               // 0 = OBEN   1023 = UNTEN
      xVal_P2 = map(xStick_P2, 0, 1023, -100, 100);


      if (yVal_P1 < -20) {         // Aussteuerung nach oben
        _Dir = UP;
      }
      else if (yVal_P1 > 20 ) {   // Aussteuerung nach unten
        _Dir = DOWN;
      }
      else if (xVal_P1 < -20) {         // Aussteuerung nach links
        _Dir = LEFT;
      }
      else if (xVal_P1 > 20) {    // Aussteuerung nach rechts
        _Dir = RIGHT;
      }
      else {
        _Dir = 0;
      }

      if (yVal_P2 < -20) {         // Aussteuerung nach oben
        _Dir = UP;
      }
      else if (yVal_P2 > 20 ) {   // Aussteuerung nach unten
        _Dir = DOWN;
      }
      else if (xVal_P2 < -20) {         // Aussteuerung nach links
        _Dir = LEFT;
      }
      else if (xVal_P2 > 20) {    // Aussteuerung nach rechts
        _Dir = RIGHT;
      }
      else {
        _Dir = 0;
      }

    }
    void motion() {
      switch (_Dir) {
        case LEFT:
          Serial.println("LEFT");
          digitalWrite(DIR_PIN_PAN, HIGH);
          analogWrite(STEP_PIN_PAN, 127);
          delay(50);
          break;

        case RIGHT:
          Serial.println("RIGHT");
          digitalWrite(DIR_PIN_PAN, LOW);
          analogWrite(STEP_PIN_PAN, 127);
          delay(50);
          break;

        case UP:
          Serial.println("UP");
          digitalWrite(DIR_PIN_TILT, HIGH);
          analogWrite(STEP_PIN_TILT, 127);
          delay(50);
          break;
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

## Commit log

2022-04-25 Introducing the STL file for the Nerf Turret
    OpenSCAD code with dimensions for the model builds.
2022-04-25 File type correction
    [NerfTurret.scad]
2022-04-25 Updating NerfTurret.scad
    Developing the NERF holder step by step...
    [NerfTurret.scad]
2022-04-26 Adding more models and connectors
    TODO: Servo Trigger mount
    [NerfTurret.scad]
2022-04-26 First STL export (incomplete version)
    [NerfTurret-ProTyp.stl]
2022-04-26 Completing the first turret prototype model!
    yeah, biatches.
    [NerfTurret.scad]
2022-04-26 First STL slice of the ProtoTyp v.1
    that's right shawty.
    [NerfTurret-ProTyp.stl]
2022-05-11 Project modules separated in files
    One file for every print..
    [NerfTurret-ProTyp-Connectors-3.scad, NerfTurret-ProTyp-Connectors-3.stl, NerfTurret-ProTyp-Fixation-4.scad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]
2022-05-13 TMC2208-Stepper driver
    Code sources to control the H bridge.
2022-05-13 Sorting finished, implementing stepper motor controls..
2022-05-14 Completing TMC2208 shematic for wiring diagram
2022-05-14 Pinout found
    Full pinout explanation for the TMC2208 stepper motor driver.
2022-05-17 Expanding documentation, adding first schematics
    So is dat.
    [SpaceInvaders-Arcade-scheme-STAGE2.fzz, SpaceInvaders-Arcade-scheme.fzz, SpaceInvaders-Materialliste.xlsx]
2022-05-24 Releasing first schematics
    [SpaceArcade-schematic.kicad_pcb, SpaceArcade-schematic.kicad_sch]
2022-05-24 Updating and adding custom components
    [SpaceArcade-schematic.kicad_sch]
2022-05-24 Fixing wiring
    Fixing driver wiring
    [SpaceArcade-schematic.kicad_sch]
2022-05-29 ProtoType #2
    Release of the second prototype model for the first test print as instructed.
    [NerfTurret-ProTyp-Connectors-3.scad, NerfTurret-ProTyp-Connectors-3.stl, NerfTurret-ProTyp-Fixation-4-v2.scad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]
2022-06-06 Documentation and dimensions for printing motor cases and adapters
2022-06-07 Next stage for the 3D printed accessories...
2022-06-07 Version 3 of the part models..
    Fuck yeah
    [SpaceParts-v3.stl]
2022-06-09 Adding single part STL files
    [Gear-Adaptor-v3.stl, Motor-PAN-Case-v3.stl, Motor-TILT-Case-v3.stl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]
2022-06-09 Adding more pictures and videos from the printed parts
2022-06-10 Release #3 of part models
    [Nerfhalter-Grip-v3.stl, Servobefestigung-v5.stl, Servohalter-v4.stl]
2022-06-13 Adding the last part models
    [Laufhalter-NERF-v2.stl, Servobefestigung-v5.stl, Stempel-L.stl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]
2022-06-15 Servo läuft, mainmenu läuft, Motor läuft
2022-06-16 Pinout for target sensors added
2022-06-16 Adding DR-YM-019 wiring diagram
2022-06-16 Adding coded OpenSCAD parts
    [NerfTurret-ProTyp-Connectors-3.scad, NerfTurret-ProTyp-Connectors-3.stl, NerfTurret-ProTyp-Fixation-4-v2.scad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]
2022-06-16 mehr Buttons und mainGame()
